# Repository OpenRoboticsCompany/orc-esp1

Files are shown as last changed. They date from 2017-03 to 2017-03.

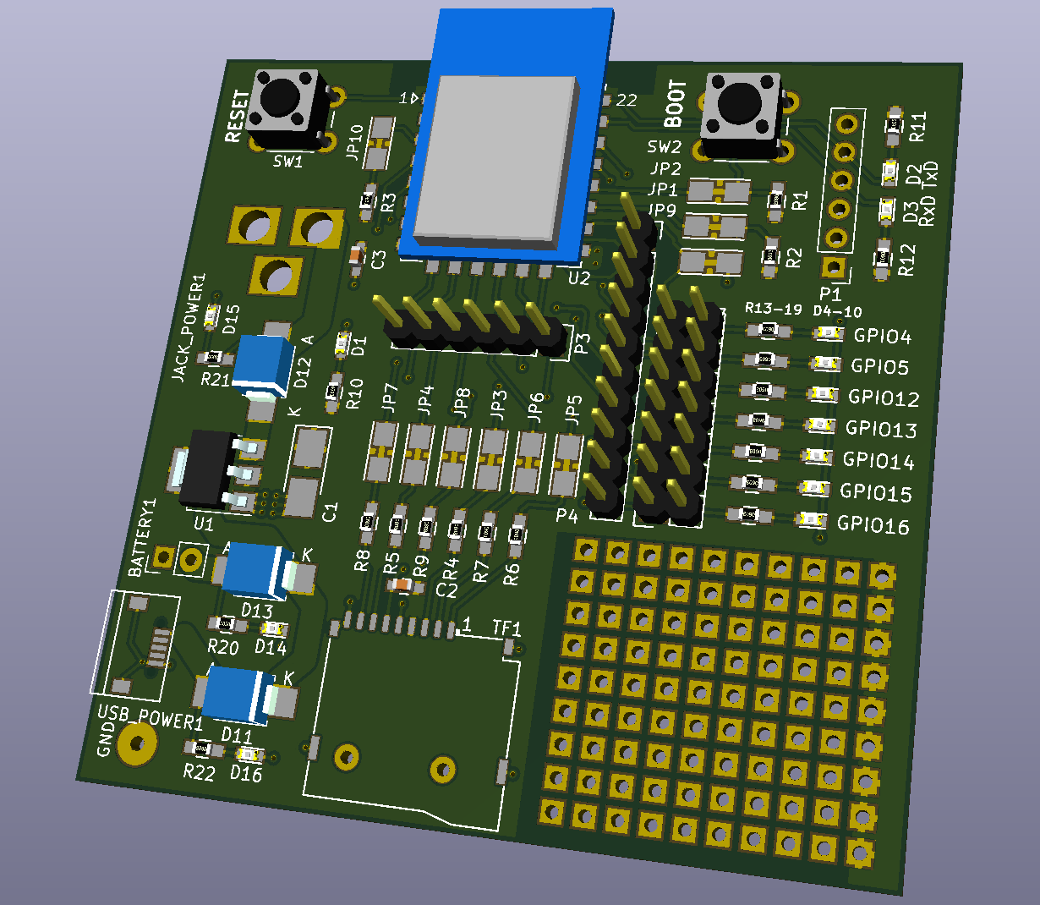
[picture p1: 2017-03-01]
images/board-3d.png

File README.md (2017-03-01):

ESP8266 Development Board
=========================

PCB 3D View

Front:

PCB Front

Back:

PCB Back

This board provides power, GPIO, and Micro SD to the commonly-available
ESP8266 wifi modules. This first revision is intended for internal use
at Open Robotics Company, but may find it's way out to the world also.

Built using [KiCad EDA](http://kicad-pcb.org/)

PCB images courtesy of OSHPark's magical preview.

Important Build Notes
---------------------

Please note that we used a nightly dev build of KiCad for this project.
You cannot open the files in the current stable version (4.0.5 as of this
writing).  We used *kicad-r7402.f631ae2-x86_64* on Windows. It's possible
that later versions will open the files, but because nightly builds are
always changing, you never know!

Copyright
---------

Designed by [Aaron Kondziela](https://aaronkondziela.com).
Copyright 2017 [Open Robotics Company LLC](https://openrobotics.company)

If any files (datasheets, etc) have been included here that are not
our original work, they are (obviously) the copyright of their respective
authors.

License
-------

This work is licensed under a Creative Commons Attribution-ShareAlike 4.0 International License.

https://creativecommons.org/licenses/by-sa/4.0/

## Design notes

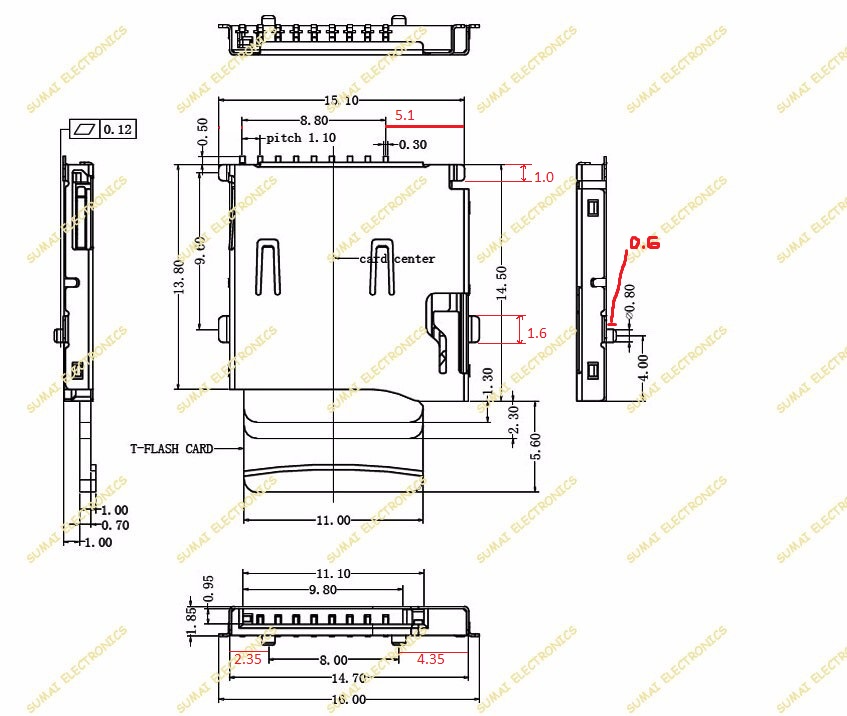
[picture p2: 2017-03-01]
micro-sd from ginkgo guangzhou e-commerce co ltd.jpg

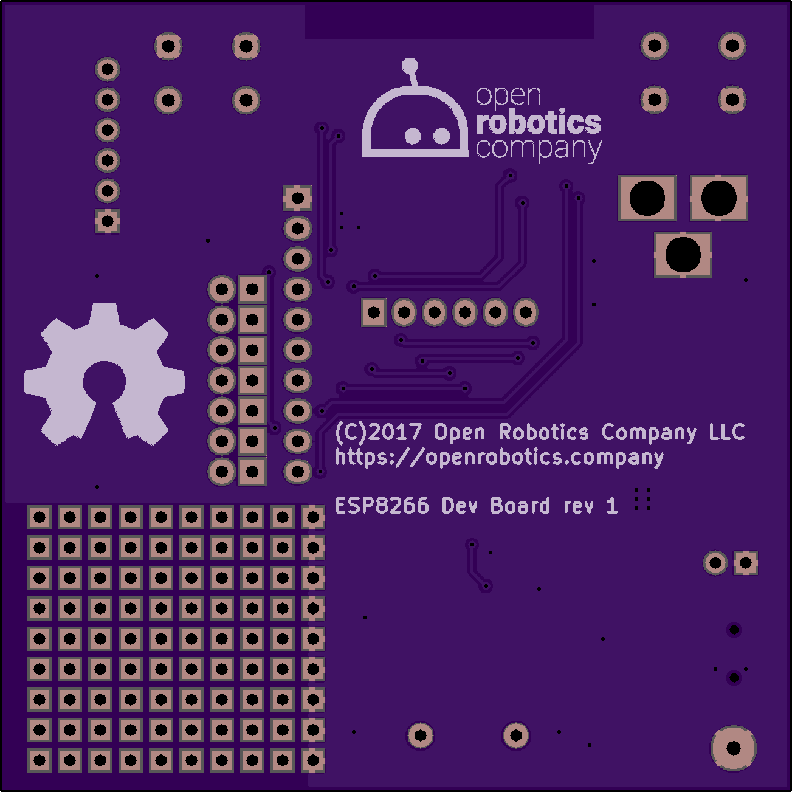
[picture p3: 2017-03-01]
images/pcb-back-oshpark.png

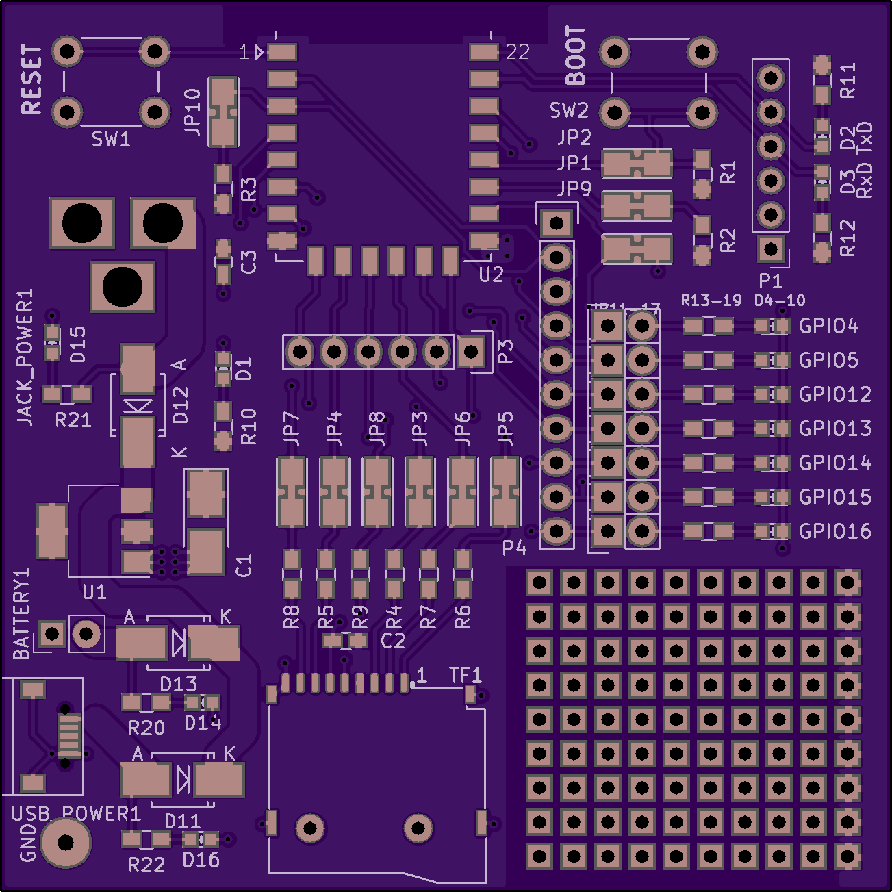
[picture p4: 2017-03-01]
images/pcb-front-oshpark.png

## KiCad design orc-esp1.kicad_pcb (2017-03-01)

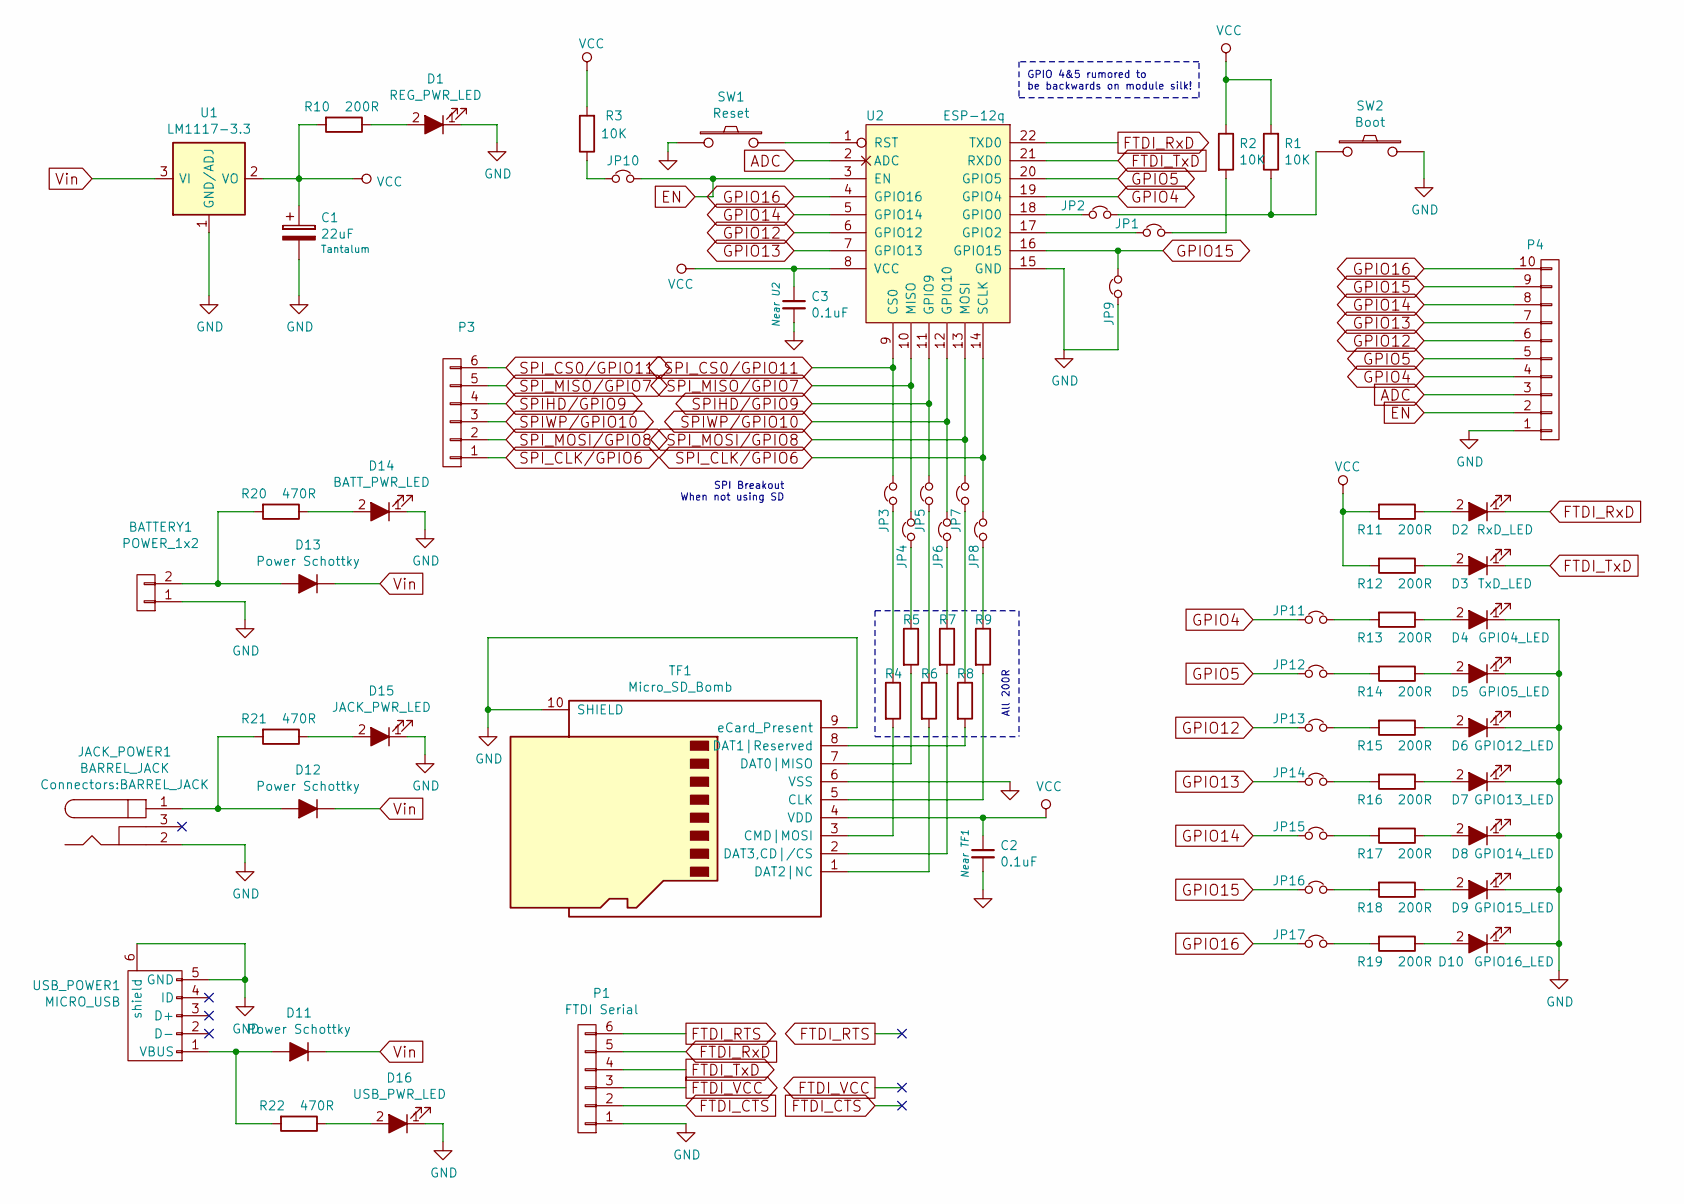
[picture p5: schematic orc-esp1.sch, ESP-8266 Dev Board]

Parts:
BATTERY1: POWER_1x2; Pin_Header_Straight_1x02_Pitch2.54mm
C1: 22uF; Tantalum_Case-B_EIA-3528-21_Hand
C2, C3: 0.1uF; C_0603_HandSoldering
D1: REG_PWR_LED; LED_0603
D2: RxD_LED; LED_0603
D3: TxD_LED; LED_0603
D4: GPIO4_LED; LED_0603
D5: GPIO5_LED; LED_0603
D6: GPIO12_LED; LED_0603
D7: GPIO13_LED; LED_0603
D8: GPIO14_LED; LED_0603
D9: GPIO15_LED; LED_0603
D10: GPIO16_LED; LED_0603
D11, D12, D13: Power Schottky; SMB_Handsoldering
D14: BATT_PWR_LED; LED_0603
D15: JACK_PWR_LED; LED_0603
D16: USB_PWR_LED; LED_0603
JACK_POWER1: BARREL_JACK
JP1: BOOT_JP3; Jumper_1206_NC_DNP
JP2: BOOT_JP; Jumper_1206_NC_DNP
JP3: SD_JP3; Jumper_1206_NC_DNP
JP4: SD_JP4; Jumper_1206_NC_DNP
JP5: SD_JP5; Jumper_1206_NC_DNP
JP6: SD_JP6; Jumper_1206_NC_DNP
JP7: SD_JP7; Jumper_1206_NC_DNP
JP8: SD_JP8; Jumper_1206_NC_DNP
JP9: BOOT_JP2; Jumper_1206_NC_DNP
JP10: EN_JP; Jumper_1206_NC_DNP
JP11: GPIO4_JP; Pin_Header_Straight_1x02
JP12: GPIO5_JP; Pin_Header_Straight_1x02
JP13: GPIO12_JP; Pin_Header_Straight_1x02
JP14: GPIO13_JP; Pin_Header_Straight_1x02
JP15: GPIO14_JP; Pin_Header_Straight_1x02
JP16: GPIO15_JP; Pin_Header_Straight_1x02
JP17: GPIO16_JP; Pin_Header_Straight_1x02
P1: FTDI Serial; Pin_Header_Straight_1x06_Pitch2.54mm
P3: CONN_01X06; Pin_Header_Straight_1x06
P4: CONN_01X10; Pin_Header_Straight_1x10
R1, R2, R3: 10K; R_0603_HandSoldering
R4, R5, R6, R7, R8, R9, R10, R11, R12, R13, R14, R15, R16, R17, R18, R19: 200R; R_0603_HandSoldering
R20, R21, R22: 470R; R_0603_HandSoldering
SW1: Reset; SW_PUSH_6mm
SW2: Boot; SW_PUSH_6mm
TF1: Micro_SD_Bomb; Sumai-Micro-SD-Bomb
U1: LM1117-3.3; SOT-223
U2: ESP-12q; ESP-12-Q
USB_POWER1: MICRO_USB; USB_Micro-B

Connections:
ADC: P4.3, U2.2 (ADC)
EN: JP10.2, P4.2, U2.3 (EN)
FTDI_CTS: P1.2
FTDI_RTS: P1.6
FTDI_RxD: D2.1 (K), P1.5, U2.22 (TXD0)
FTDI_TxD: D3.1 (K), P1.4, U2.21 (RXD0)
FTDI_VCC: P1.3
GND: BATTERY1.1 (eeGND), C1.2, C2.2, C3.2, D1.1 (K), D4.1 (K), D5.1 (K), D6.1 (K), D7.1 (K), D8.1 (K), D9.1 (K), D10.1 (K), D14.1 (K), D15.1 (K), D16.1 (K), JACK_POWER1.2, JACK_POWER1.3, JP9.1, P1.1, P4.1, SW1.1, SW2.2, TF1.6 (VSS), TF1.9 (eCard_Present), TF1.10 (SHIELD), U1.1 (GND/ADJ), U2.15 (GND), USB_POWER1.5 (GND), USB_POWER1.6 (shield); also elsewhere on the board
GPIO4: JP11.1, P4.4, U2.19 (GPIO4)
GPIO5: JP12.1, P4.5, U2.20 (GPIO5)
GPIO12: JP13.1, P4.6, U2.6 (GPIO12)
GPIO13: JP14.1, P4.7, U2.7 (GPIO13)
GPIO14: JP15.1, P4.8, U2.5 (GPIO14)
GPIO15: JP9.2, JP16.1, P4.9, U2.16 (GPIO15)
GPIO16: JP17.1, P4.10, U2.4 (GPIO16)
unnamed: BATTERY1.2 (+BAT), D13.2 (A), R20.2
unnamed: D1.2 (A), R10.1
unnamed: D2.2 (A), R11.1
unnamed: D3.2 (A), R12.1
unnamed: D4.2 (A), R13.1
unnamed: D5.2 (A), R14.1
unnamed: D6.2 (A), R15.1
unnamed: D7.2 (A), R16.1
unnamed: D8.2 (A), R17.1
unnamed: D9.2 (A), R18.1
unnamed: D10.2 (A), R19.1
unnamed: D11.2 (A), R22.2, USB_POWER1.1 (VBUS)
unnamed: D12.2 (A), JACK_POWER1.1, R21.2
unnamed: D14.2 (A), R20.1
unnamed: D15.2 (A), R21.1
unnamed: D16.2 (A), R22.1
unnamed: JP1.1, U2.17 (GPIO2)
unnamed: JP1.2, R2.2
unnamed: JP2.1, U2.18 (GPIO0)
unnamed: JP2.2, R1.1, SW2.1
unnamed: JP3.1, R4.1
unnamed: JP4.1, R5.1
unnamed: JP5.1, R6.1
unnamed: JP6.1, R7.1
unnamed: JP7.1, R8.1
unnamed: JP8.1, R9.1
unnamed: JP10.1, R3.1
unnamed: JP11.2, R13.2
unnamed: JP12.2, R14.2
unnamed: JP13.2, R15.2
unnamed: JP14.2, R16.2
unnamed: JP15.2, R17.2
unnamed: JP16.2, R18.2
unnamed: JP17.2, R19.2
unnamed: R4.2, TF1.3 (CMD|MOSI)
unnamed: R5.2, TF1.7 (DAT0|MISO)
unnamed: R6.2, TF1.1 (DAT2|NC)
unnamed: R7.2, TF1.2 (DAT3,CD|/CS)
unnamed: R8.2, TF1.8 (DAT1|Reserved)
unnamed: R9.2, TF1.5 (CLK)
unnamed: SW1.2, U2.1 (RST)
SPIHD/GPIO9: JP5.2, P3.4, U2.11 (GPIO9)
SPIWP/GPIO10: JP6.2, P3.3, U2.12 (GPIO10)
SPI_CLK/GPIO6: JP8.2, P3.1, U2.14 (SCLK)
SPI_CS0/GPIO11: JP3.2, P3.6, U2.9 (CS0)
SPI_MISO/GPIO7: JP4.2, P3.5, U2.10 (MISO)
SPI_MOSI/GPIO8: JP7.2, P3.2, U2.13 (MOSI)
VCC: C1.1, C2.1, C3.1, R1.2, R2.1, R3.2, R10.2, R11.2, R12.2, TF1.4 (VDD), U1.2 (VO), U1.4 (VO), U2.8 (VCC)
Vin: D11.1 (K), D12.1 (K), D13.1 (K), U1.3 (VI)

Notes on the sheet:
GPIO 4&5 rumored to be backwards on module silk!
All 200R
SPI Breakout When not using SD

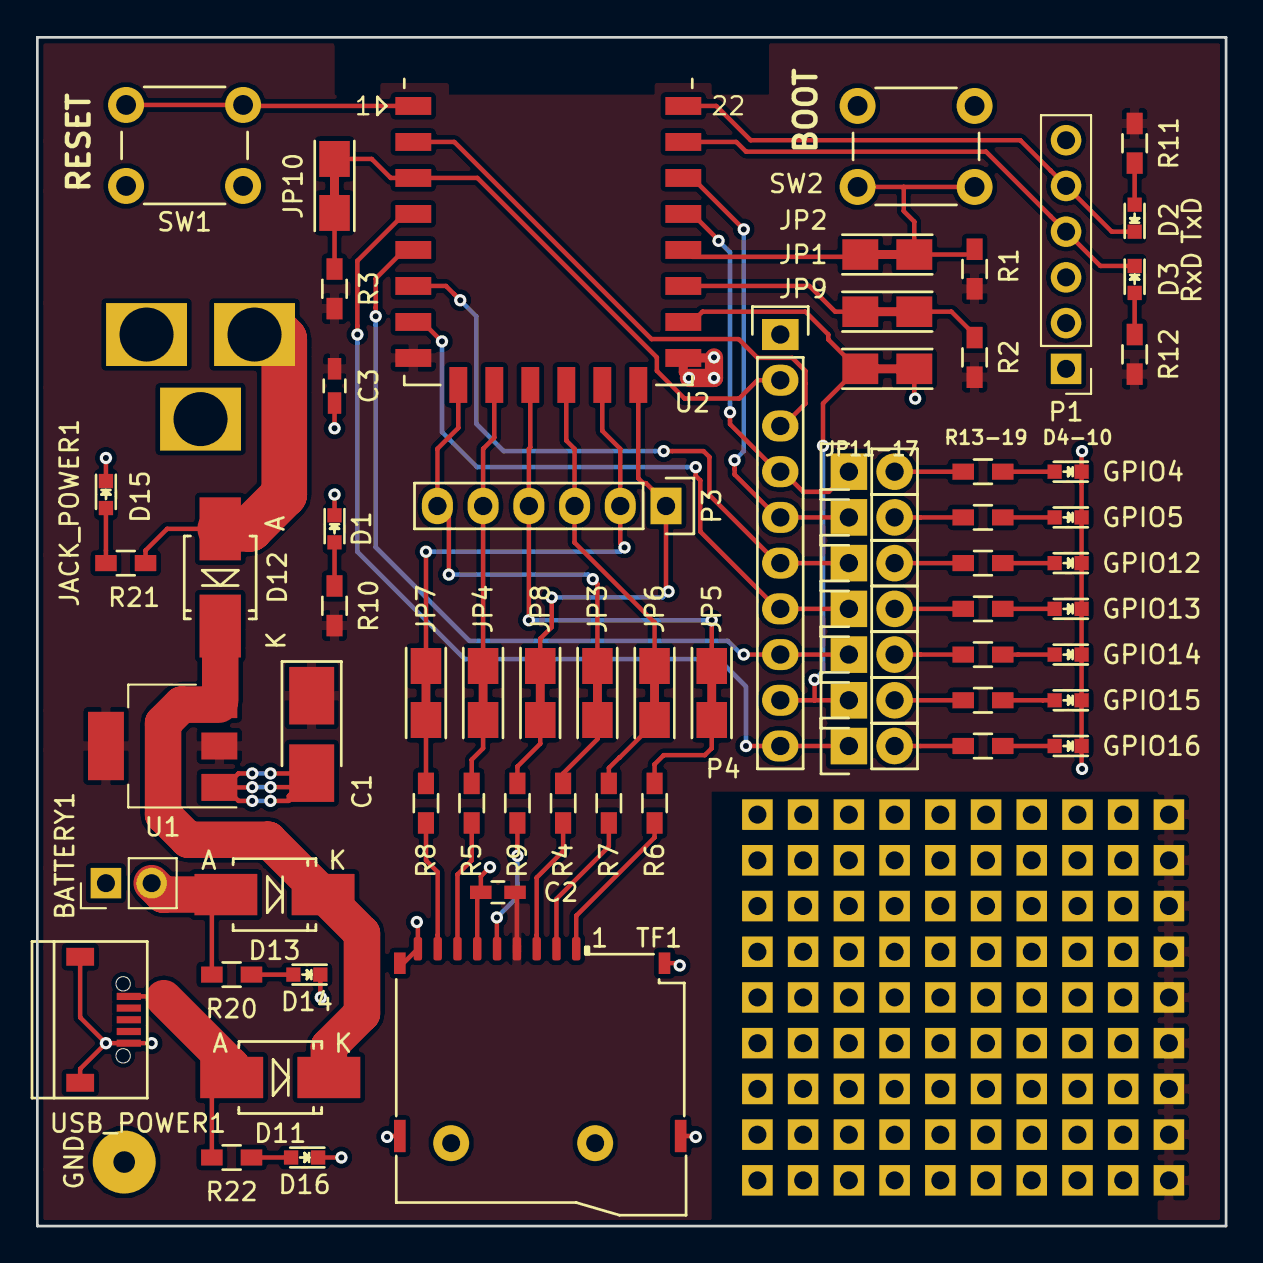
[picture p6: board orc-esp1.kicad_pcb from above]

Board: 2 copper layers, 66.0 x 66.0 mm, 70 parts (0 on the bottom side), 61 nets.

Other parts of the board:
GND: GND; SolderWirePad_single_1-2mmDrill

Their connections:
GND: GND.1; also elsewhere on the board

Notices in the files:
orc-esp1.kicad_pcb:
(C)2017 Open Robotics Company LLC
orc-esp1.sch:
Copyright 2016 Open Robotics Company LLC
